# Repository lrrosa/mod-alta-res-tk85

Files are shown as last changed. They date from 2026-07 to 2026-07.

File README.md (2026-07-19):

# Mod Alta Resolução para o TK-85 ("Maldonado")

Reconstrução em **KiCad 10** do esquema elétrico da modificação de alta-resolução
gráfica para o **TK-85** (clone brasileiro do Sinclair ZX81), publicada por
**Milton Maldonado Jr.** na revista *Microhobby*.

O circuito acrescenta um framebuffer gráfico de alta resolução ao TK-85: três SRAMs
6116 compartilham o espaço de endereços da ROM principal (2364 — que contém o BASIC
e também as tabelas de caracteres) e são varridas por contadores sincronizados com a
geração de vídeo, dando uma definição comparável à de micros bem mais caros da época.

> **Status:** esquema verificado (ERC 0/0), PCB roteada (DRC 0/0) e Gerbers prontos
> para fabricação — falta montar e testar em hardware real.
> Veja [Estado do projeto](#estado-do-projeto).

---

## Estrutura do repositório

```
mod-alta-res-tk85/
├── kicad/                     Projeto KiCad 10
│   ├── mod_tk85_hires.kicad_sch    Esquema (folha única)
│   ├── mod_tk85_hires.kicad_pcb    Placa (roteada, 2 camadas, DRC limpo)
│   ├── mod_tk85_hires.kicad_pro    Projeto
│   ├── sym-lib-table               Tabela de símbolos (caminhos ${KIPRJMOD})
│   └── sym/                        Símbolos personalizados (ROM 2364, SRAM 6116)
├── esquemas/                  Esquema e placa exportados (PDF e SVG)
├── fabricacao/                Gerbers + furação (zip pronto para fábrica)
├── docs/                      Documentação, errata, BOM, mecânica
└── README.md
```

## Como abrir

Abra `kicad/mod_tk85_hires.kicad_pro` no KiCad 10. Os símbolos das memórias vêm da
biblioteca local em `kicad/sym/` (referenciada por caminho relativo `${KIPRJMOD}`, de
modo que o projeto pode ser movido ou clonado sem quebrar). Os demais símbolos (74xx,
Device, Connector, power) vêm das bibliotecas padrão do KiCad.

## Como funciona (resumo)

| Bloco | CI | Função |
|---|----|---|
| Framebuffer | U1–U3 (6116) | 3× 2 KB de SRAM gráfica, no espaço das tabelas de caracteres |
| ROM principal | U4 (2364) | ROM original do TK-85 (BASIC + caracteres), remanejada para a placa do mod |
| Contadores de vídeo | U5, U6 (74LS93) | Geram o endereço de varredura sincronizado ao vídeo |
| Multiplexador | U7 (74LS157) | Chaveia endereço: CPU (RFSH=1) × contadores (RFSH=0) |
| Decodificador | U8 (74LS138) | Seleciona qual das 3 SRAMs (`/CS0..2`) via A11/A12 |
| Cola lógica | U9 (74LS00) | Inversor de A14 para gerar `RAM CS` |
| Ajuste de reset | RV1 (22K) | Trimpot de temporização do reset dos contadores (errata) |

A conexão física com o TK-85 é feita por um **interposer pass-through**: os dois
pentes de 12 pinos (`IC2_PINS_1_12`, `IC2_PINS_13_24`) encaixam no soquete da ROM
principal (IC2) do TK-85, e a ROM 2364 encaixa por cima — cada pino do soquete é
eletricamente o mesmo nó do pino correspondente da ROM.

Descrição detalhada em [`docs/descricao-circuito.md`](docs/descricao-circuito.md).

## Errata

O artigo tem alguns erros, omissões e ambiguidades, já **corrigidos** aqui. Não os
"desfaça" comparando com a revista. Detalhes em
[`docs/correcoes-errata.md`](docs/correcoes-errata.md). Em resumo:

- `/WE` das 6116 → `WR` do Z80 (pino 22); `/OE` das 6116 → GND (omissão do artigo).
- Trimpot de 15–22 K no reset dos dois 74LS93 (`RV1`).
- Pino 9 do primeiro 74LS93 → **pino 5** do 74LS157 (o texto do artigo diz pino 9).
- `/CS` da ROM (pino 20 do IC2) ligado à ROM `U4` — necessário porque nesta
  implementação a ROM é remanejada para a placa do mod.

## Estado do projeto

- [x] Esquema elétrico em KiCad 10, com ERC limpo (0 erros / 0 avisos)
- [x] Nets com nomes significativos, desacoplamento e entradas não usadas amarradas
- [x] BOM ([`docs/bom.csv`](docs/bom.csv))
- [x] PCB: contorno (medido sobre a placa real) e posicionamento — ver
      [`docs/mecanica.md`](docs/mecanica.md)
- [x] PCB: roteamento completo em 2 camadas, DRC zerado (0 violações elétricas,
      0 pads desconectados); silk revisado
- [x] Gerbers e furação prontos para fabricação
      ([`fabricacao/`](fabricacao/))
- [ ] Montagem e teste em hardware real

## Créditos

- **Circuito original:** Milton Maldonado Jr. (*Microhobby*).
- **Reconstrução do esquema em KiCad:** Leonardo Roman da Rosa.

## Licença

Este projeto de hardware é licenciado sob a **CERN Open Hardware Licence v2 —
Strongly Reciprocal** (`CERN-OHL-S-2.0`). Veja o arquivo [`LICENSE`](LICENSE).

Conforme a seção 3.3 da licença, a localização da fonte (*Source Location*) deste
projeto é: <https://github.com/lrrosa/mod-alta-res-tk85>. Se você distribuir produtos
ou projetos derivados, mantenha as atribuições e disponibilize as fontes completas
sob a mesma licença.

> O material de referência original (o artigo da *Microhobby* e os datasheets dos
> componentes) **não** é redistribuído aqui por ser protegido por direitos autorais.
> Veja [`docs/referencias.md`](docs/referencias.md).

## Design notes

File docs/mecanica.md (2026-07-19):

# Mecânica — contorno, alturas e empilhamento

Este documento registra as medidas físicas que definiram o contorno da placa e o
esquema de montagem do interposer. As medidas foram tiradas de uma foto calibrada da
placa do TK-85 (calibração pelo passo de 2,54 mm dos DIPs; escala conferida no
DIP-40 do Z80 — erro estimado ±2–3%).

## Sistema de coordenadas

Tudo é medido em **mm relativos ao centro do IC2** (a ROM principal), com
+x para leste (em direção ao Z80) e +y para sul (em direção ao teclado). No arquivo
`kicad/mod_tk85_hires.kicad_pcb`, o centro do IC2 corresponde à posição absoluta
(150, 100).

## Contorno (forma de T)

- **Língua** (sobre o IC2): x −11,1…+10 / y −20…+17,5 — carrega os dois pentes do
  interposer, `U9` e `U6`.
- **Corpo**: x −70…+35,6 / y +17,5…+59 — paira sobre as fileiras de TTL (IC17…) e
  de RAM (IC30–37) do TK-85.
- **Recorte SE**: para x > +15,5 o corpo pára em y = +44, desviando do capacitor
  de tântalo ("gota") ao lado do IC9.

## Obstáculos altos medidos (sob ou ao lado da placa)

| Obstáculo | Posição (mm rel. IC2) | Altura aprox. | Situação |
|---|---|---|---|
| Capacitor azul deitado | x +11,5…+24,5 / y −17…−8 | ~10–11 mm | **Fora** do contorno (a língua pára em x = +10) |
| 2716 + soquete (IC3) | x −31…−12,5 / y −15…+17 | ~13 mm | **Fora** (corpo começa em y = +17,5) |
| Z80 | x +36,7… | — | Fora (borda leste em +35,6, folga ~1 mm) |
| Capacitor "gota" | x +17…+20,5 / y +46…+56 | ~9 mm | Fora (recorte SE) |
| ICs 30–37 **soquetados** | y ≈ +42…+61 | ~8–9,5 mm | **Sob a placa** — ver empilhamento |
| Fileira de TTL (IC17…) | y ≈ +17,5…+35 | ~4,5 mm | Sob a placa, baixa |

## Empilhamento do interposer e teto do gabinete

**Medições no gabinete real (2026-07-18):** sobram **~12 mm** livres tanto acima da
ROM (IC2) quanto acima dos ICs 30–37. Todos esses CIs estão **soquetados** de
fábrica (soquetes de lâmina marrons, ~3,5–4 mm — inclusive o IC2 e o 2716), com o
topo a ~8–9,5 mm da placa-mãe. O teto útil é portanto de **~20–21 mm** em toda a
região ocupada pela placa do mod.

**Pilha adotada** (contorno atual mantido):

| Camada | Altura acumulada sobre a placa-mãe |
|---|---|
| Soquete existente do IC2 (lâmina, de fábrica) | ~3,5–4 mm |
| Soquete torneado extra (espaçador) | ~7,5–8 mm |
| Pentes do interposer sob a placa do mod | vão total **~10–11 mm** |
| Placa do mod (1,6 mm) | ~12–13 mm |
| CIs do mod **soldados** (~4,5 mm) | topo a **~16,5–17 mm** ✓ |
| ROM em soquete de lâmina baixo na placa do mod | topo a **~20 mm** — no limite, cabe |

- O vão de ~10–11 mm passa sobre os ICs 30–37 soquetados (~8–9,5 mm) com folga de
  1–2,5 mm.
- Os CIs do mod (TTLs e 6116) devem ser **soldados sem soquete** para preservar o
  teto. Só a ROM — o chip original transplantado — usa soquete, de lâmina e perfil
  baixo.
- Pino torneado encaixa em soquete de lâmina, mas confira o aperto do contato; se
  ficar frouxo, vale trocar o soquete do IC2 por um torneado.
- Estabilidade: a placa fica em balanço apoiada só no soquete do IC2. Recomenda-se
  um **pé de apoio** (espaçador de nylon com base adesiva, ou bloco de espuma) sob
  o canto sudoeste do corpo.

## Montagem da ROM sobre a língua (interposer)

Os dois pentes do interposer estão em geometria DIP-24 (600 mil) e carregam
**exatamente as mesmas nets, pino a pino, do soquete `U4`** — consequência do
interposer pass-through. Ou seja: a ROM 2364 pode ser encaixada **diretamente
sobre a língua**, em cima de `U9` e `U6`, dispensando o soquete `U4` (que fica
despopulado; **nunca** popular os dois ao mesmo tempo com duas ROMs).

A peça que realiza isso é um **soquete DIP-24 torneado com terminais wire-wrap**
(postes de 2 ou 3 níveis, 10–17 mm): o corpo fica no topo da placa como soquete da
ROM, e os postes atravessam a placa e viram os pinos macho do interposer por baixo.
Exemplos: Mill-Max série 123 (123-93-624-41-001000), Preci-Dip 110-93-624-41-001000;
como alternativa mais fácil de encontrar, **duas barras SIP 1×12 torneadas de
terminal longo** ("round pin female header, wire-wrap/long pin") cortadas na medida.

Alturas nessa configuração (**medidas sobre a placa-mãe do TK-85**; topo da placa
do mod fica a ~11,6–12,6 mm):

- Assento do soquete wire-wrap: ~4,5–5 mm sobre a placa do mod — os CIs
  `U9`/`U6` soldados (~4,3 mm) passam por baixo **no limite** (folga 0,2–0,7 mm).
- Topo da ROM: 11,6–12,6 + 4,5–5 + 4,5 ≈ **20,6–22 mm** — **igual ou acima do
  teto de ~20–21 mm**. Com um soquete extra empilhado (para dar folga sobre
  U9/U6), vai a ~24 mm — **não cabe de jeito nenhum**.
- **Conclusão: com o teto medido, esta opção é desaconselhada.** Fica registrada
  pela equivalência elétrica (vale para gabinetes modificados ou uso sem tampa);
  a montagem recomendada é a ROM no soquete `U4` (topo a ~19–20,6 mm).
- Por baixo, os postes atravessam o soquete-espaçador e entram no soquete original
  do IC2. Postes wire-wrap são quadrados (~0,64 mm): encaixam bem em soquetes de
  **lâmina** (o espaçador e o soquete original do TK-85); evite usar soquete
  torneado como espaçador nesse caso, pois o furo torneado é para pino redondo.

## RV1 — ajuste por cima

`RV1` usa o Bourns **3266W** (ajuste pelo topo). A variante lateral (3266P) foi
descartada porque o parafuso ficava voltado para o interior da placa, inacessível
com os soquetes vizinhos populados.

**Altura:** o 3266W tem **8,26 mm** de corpo — topo a ~19,9–20,9 mm sobre a
placa-mãe, no **mesmo grupo crítico da ROM** frente ao teto de ~20–21 mm. Antes de
soldar, faça um ensaio a seco: com a pilha do interposer montada e a tampa
fechando, é preciso haver **≥ 8,3 mm** livres acima do topo da placa do mod na
região do RV1. Se faltar, os planos B são: (a) trocar por um trimpot de volta
única com ajuste por cima e ~5 mm de altura (ex.: Piher PT-6-V — exige retrabalho
dos pads naquele canto), ou (b) montar o trimpot fora da placa, por 3 fios curtos
nos pads (estilo "teia de aranha", fiel ao artigo).

## Roteamento

Duas camadas, roteado por autorouter (Freerouting 2.2.4) com acabamento manual,
DRC do KiCad **zerado** (0 violações elétricas, 0 pads desconectados):

- Trilhas de sinal **0,25 mm**; `+5V` e `GND` **0,6 mm**; isolamento mínimo
  **0,13 mm**; vias 0,6/0,3 mm — tudo dentro da capacidade de qualquer fabricante
  comum de PCB (limite típico 0,127 mm).
- `GND` é roteado como trilha **e** reforçado por pours nas duas faces.
- A checagem `starved_thermal` foi rebaixada para aviso: quatro pads de GND ficam
  com um único raio térmico da zona, mas todos têm também conexão plena por
  trilha — eletricamente sólidos; o alívio térmico ainda ajuda na soldagem.

## J1 (sinais do TK-85)

Barra de 8 pinos em ângulo reto na borda sul, com os pinos apontando para a frente
do micro (lado do teclado). Os fios voadores para A14/A15/MREQ/RFSH/WR (CPU),
RAM CS, clock de vídeo (IC-11) e clock de 60 Hz (IC-24) saem por ali.

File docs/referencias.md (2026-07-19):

# Referências

O material de referência abaixo foi usado na reconstrução do esquema. Ele **não é
redistribuído neste repositório** por ser protegido por direitos autorais — está
listado apenas para atribuição e para quem quiser buscá-lo nas fontes originais.

## Artigo original

- **"Alta-Resolução no TK-85"** (Partes I, II e III) — Milton Maldonado Jr., revista
  *Microhobby*. É a descrição do circuito e do procedimento de montagem/ajuste que este
  projeto implementa. Disponível para consulta no acervo do Datassette:
  <https://datassette.org/pt-br/revistas/informatica/br-brasil/microhobby/projetos/alta-resolucao-no-tk-85>

## Datasheets dos componentes

- ROM **2364** (ROM de máscara de 8 KB — a ROM principal do TK-85, IC2, com o
  BASIC/sistema e as tabelas de caracteres). Datasheet MOS 2364 (fev. 1980):
  <https://archive.org/details/mos_2364_rom_feb_1980>
- SRAM **6116** (2 KB × 8) — as três memórias do framebuffer. Datasheet Renesas
  6116SA/LA: <https://www.renesas.com/en/document/dst/6116sala-data-sheet>
- Famílias TTL **74LS00, 74LS93, 74LS138, 74LS157** — datasheets dos respectivos
  fabricantes.

## Placa hospedeira

- **TK-85 revisão K** — esquema da placa do TK-85, **redesenhado por Daniel José
  Viana ("Danjovic")**; não é o esquema original de fábrica. Usado como referência
  para localizar os sinais tomados por `J1`: A14, A15, MREQ, RFSH, WR, clock de
  vídeo e clock de 60 Hz. Disponível no acervo do Datassette:
  <https://datassette.org/pt-br/manuais/microdigital-eletronica/tk82c-tk83-tk85/hardware/br-brasil/tk85-esquema-eletrico-rev-k>

## Nota sobre direitos autorais

Este repositório contém apenas trabalho derivado próprio (o esquema em KiCad e a
documentação). Os documentos originais acima pertencem aos seus respectivos autores e
detentores de direitos.

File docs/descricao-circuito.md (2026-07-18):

# Descrição do circuito

Este documento descreve o funcionamento do mod e o significado dos sinais do esquema.
A fonte da lógica é o artigo original de Milton Maldonado Jr.; a nomenclatura de nets
abaixo foi padronizada nesta reconstrução.

## Ideia geral

O IC2 do TK-85 é a **ROM principal** do micro (2364, 8 KB): contém o BASIC/sistema e
também as tabelas de bitmap dos caracteres, lidas pela lógica de vídeo durante a
geração da imagem (como no ZX81). O mod intercepta o soquete dessa ROM e acrescenta
**três SRAMs 6116** (6 KB) mapeadas de forma a substituir as tabelas de caracteres
durante a varredura. Assim é possível redefinir dinamicamente os bitmaps (POKE nas
6116) e obter 256×192 pixels de alta resolução, sem consumir os 16 KB de RAM do
usuário.

O ponto delicado é o **endereçamento**: durante a geração da imagem, quem endereça as
memórias não é a CPU, e sim contadores sincronizados ao vídeo.

## Blocos

### Framebuffer — U1, U2, U3 (6116)
Três SRAMs de 2 KB. Endereços baixos `A0–A8` são compartilhados com a ROM (vêm do
soquete do IC2). `A9`/`A10` de cada SRAM vêm do multiplexador (`RAM_A9`, `RAM_A10`).
Seleção de chip por `/CS0`, `/CS1`, `/CS2` (do 74LS138). `/WE = WR` do Z80, `/OE = GND`
(ver errata). Dados `D0–D7` compartilhados com a ROM e o soquete.

### ROM principal — U4 (2364)
A ROM original do TK-85 (BASIC + tabelas de caracteres), remanejada para a placa do
mod. Endereços `A0–A8` iguais aos das SRAMs; `A9–A12` vêm direto da CPU (soquete).
`/CS = CS_ROM` (pino 20 do soquete).

### Contadores de vídeo — U5, U6 (74LS93)
- `U5` (CI-A): recebe o **clock de vídeo** (`CLK_VID`) em CP0; Q0→CP1 forma o contador
  de 4 bits; Q3 (`CT_CARRY`) faz o "carry" para o CI-B.
- `U6` (CI-B): clocado por `CT_CARRY`; saídas `VQ0–VQ3` são o endereço de vídeo que
  alimenta o multiplexador.
- Reset: `R0(1)` dos dois CIs no nó `CNT_RST`, alimentado pelo clock de 60 Hz através do
  trimpot `RV1`. `R0(2)` de ambos amarrado a `+5V` (determinístico; era flutuante).

### Multiplexador de endereços — U7 (74LS157)
Seleciona, conforme `RFSH`:
- `RFSH = 1` (CPU acessando as memórias): passa `A9–A12` da CPU.
- `RFSH = 0` (geração de imagem): passa `VQ0–VQ3` dos contadores.

Saídas: `RAM_A9`/`RAM_A10` (para as SRAMs) e `SEL_A0`/`SEL_A1` (para o decodificador).
Enable `/E` (pino 15) em GND (sempre ativo).

### Decodificador de banco — U8 (74LS138)
Entradas `A0/A1 = SEL_A0/SEL_A1` (o par A11/A12 já multiplexado), `A2 = GND`. Habilitação
`G1 = A15`, `/G2A = A14`, `/G2B = MREQ`. Saídas `O0–O2 = /CS0../CS2`. `O3–O7` não usadas.

### Cola lógica — U9 (74LS00)
Apenas a porta A é usada: `NAND(A14, A14) = /A14`, que gera o sinal `RAM CS` de volta ao
TK-85. As outras três portas têm entradas amarradas a GND e saídas em no-connect.

### Interface com o TK-85 — J1
Barra de 8 pinos com os sinais tomados de outros pontos da placa do TK-85:
`A14, A15, RAM CS, MREQ, RFSH, WR, CLK_60, CLK_VID`.

## Referência de nets

| Net | Significado |
|-----|---|
| `A0`–`A8` | Endereços baixos compartilhados (soquete → ROM + SRAMs) |
| `A9`–`A12` | Endereços altos da CPU (soquete → ROM + entradas `I1` do mux) |
| `D0`–`D7` | Barramento de dados (soquete ↔ ROM ↔ SRAMs) |
| `CS_ROM` | `/CS` da ROM 2364 (pino 20 do IC2) |
| `RAM_A9`, `RAM_A10` | Endereços A9/A10 das SRAMs (saída do mux) |
| `SEL_A0`, `SEL_A1` | A11/A12 multiplexados → entradas do decodificador |
| `CS0`, `CS1`, `CS2` | Seleção das três SRAMs (`/CS`, do 74LS138) |
| `VQ0`–`VQ3` | Endereço de vídeo (saídas do contador CI-B) |
| `CT_CARRY` | Q3 do CI-A → CP0 do CI-B (cascata dos contadores) |
| `CTA_Q0` | Q0→CP1 do CI-A (realimentação interna do contador) |
| `CNT_RST` | Reset dos contadores (via trimpot `RV1`, do clock de 60 Hz) |
| `RFSH`, `MREQ`, `WR` | Sinais de controle do Z80 |
| `A14`, `A15` | Endereços altos da CPU para o decodificador/cola |
| `RAM CS` | Sinal gerado (`/A14`) devolvido ao TK-85 |
| `CLK_VID`, `CLK_60` | Clock de vídeo (≈15750 Hz) e clock de 60 Hz |

## Desacoplamento

Um capacitor de 100 nF por CI (`C1–C9`) e um eletrolítico de 47 µF de bulk (`C10`).
São acréscimo deste projeto em relação ao artigo — ver a seção 5 de
[`correcoes-errata.md`](correcoes-errata.md).

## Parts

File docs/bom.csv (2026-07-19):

Ref | Valor | Footprint | Qtd
C1-C9 | 100nF | Capacitor_THT:C_Disc_D5.0mm_W2.5mm_P5.00mm | 9
C10 | 47uF | Capacitor_THT:CP_Radial_D6.3mm_P2.50mm | 1
IC2_PINS_1_12 | IC2 pinos 1-12 | Connector_PinSocket_2.54mm:PinSocket_1x12_P2.54mm_Vertical | 1
IC2_PINS_13_24 | IC2 pinos 13-24 | Connector_PinSocket_2.54mm:PinSocket_1x12_P2.54mm_Vertical | 1
J1 | Sinais do TK-85 | Connector_PinHeader_2.54mm:PinHeader_1x08_P2.54mm_Horizontal | 1
RV1 | 22K | Potentiometer_THT:Potentiometer_Bourns_3266W_Vertical | 1
U1-U3 | 6116 | Package_DIP:DIP-24_W15.24mm_Socket | 3
U4 | 2364 (IC2) | Package_DIP:DIP-24_W15.24mm_Socket | 1
U5,U6 | 74LS93 | Package_DIP:DIP-14_W7.62mm_Socket | 2
U7 | 74LS157 | Package_DIP:DIP-16_W7.62mm_Socket | 1
U8 | 74LS138 | Package_DIP:DIP-16_W7.62mm_Socket | 1
U9 | 74LS00 | Package_DIP:DIP-14_W7.62mm_Socket | 1

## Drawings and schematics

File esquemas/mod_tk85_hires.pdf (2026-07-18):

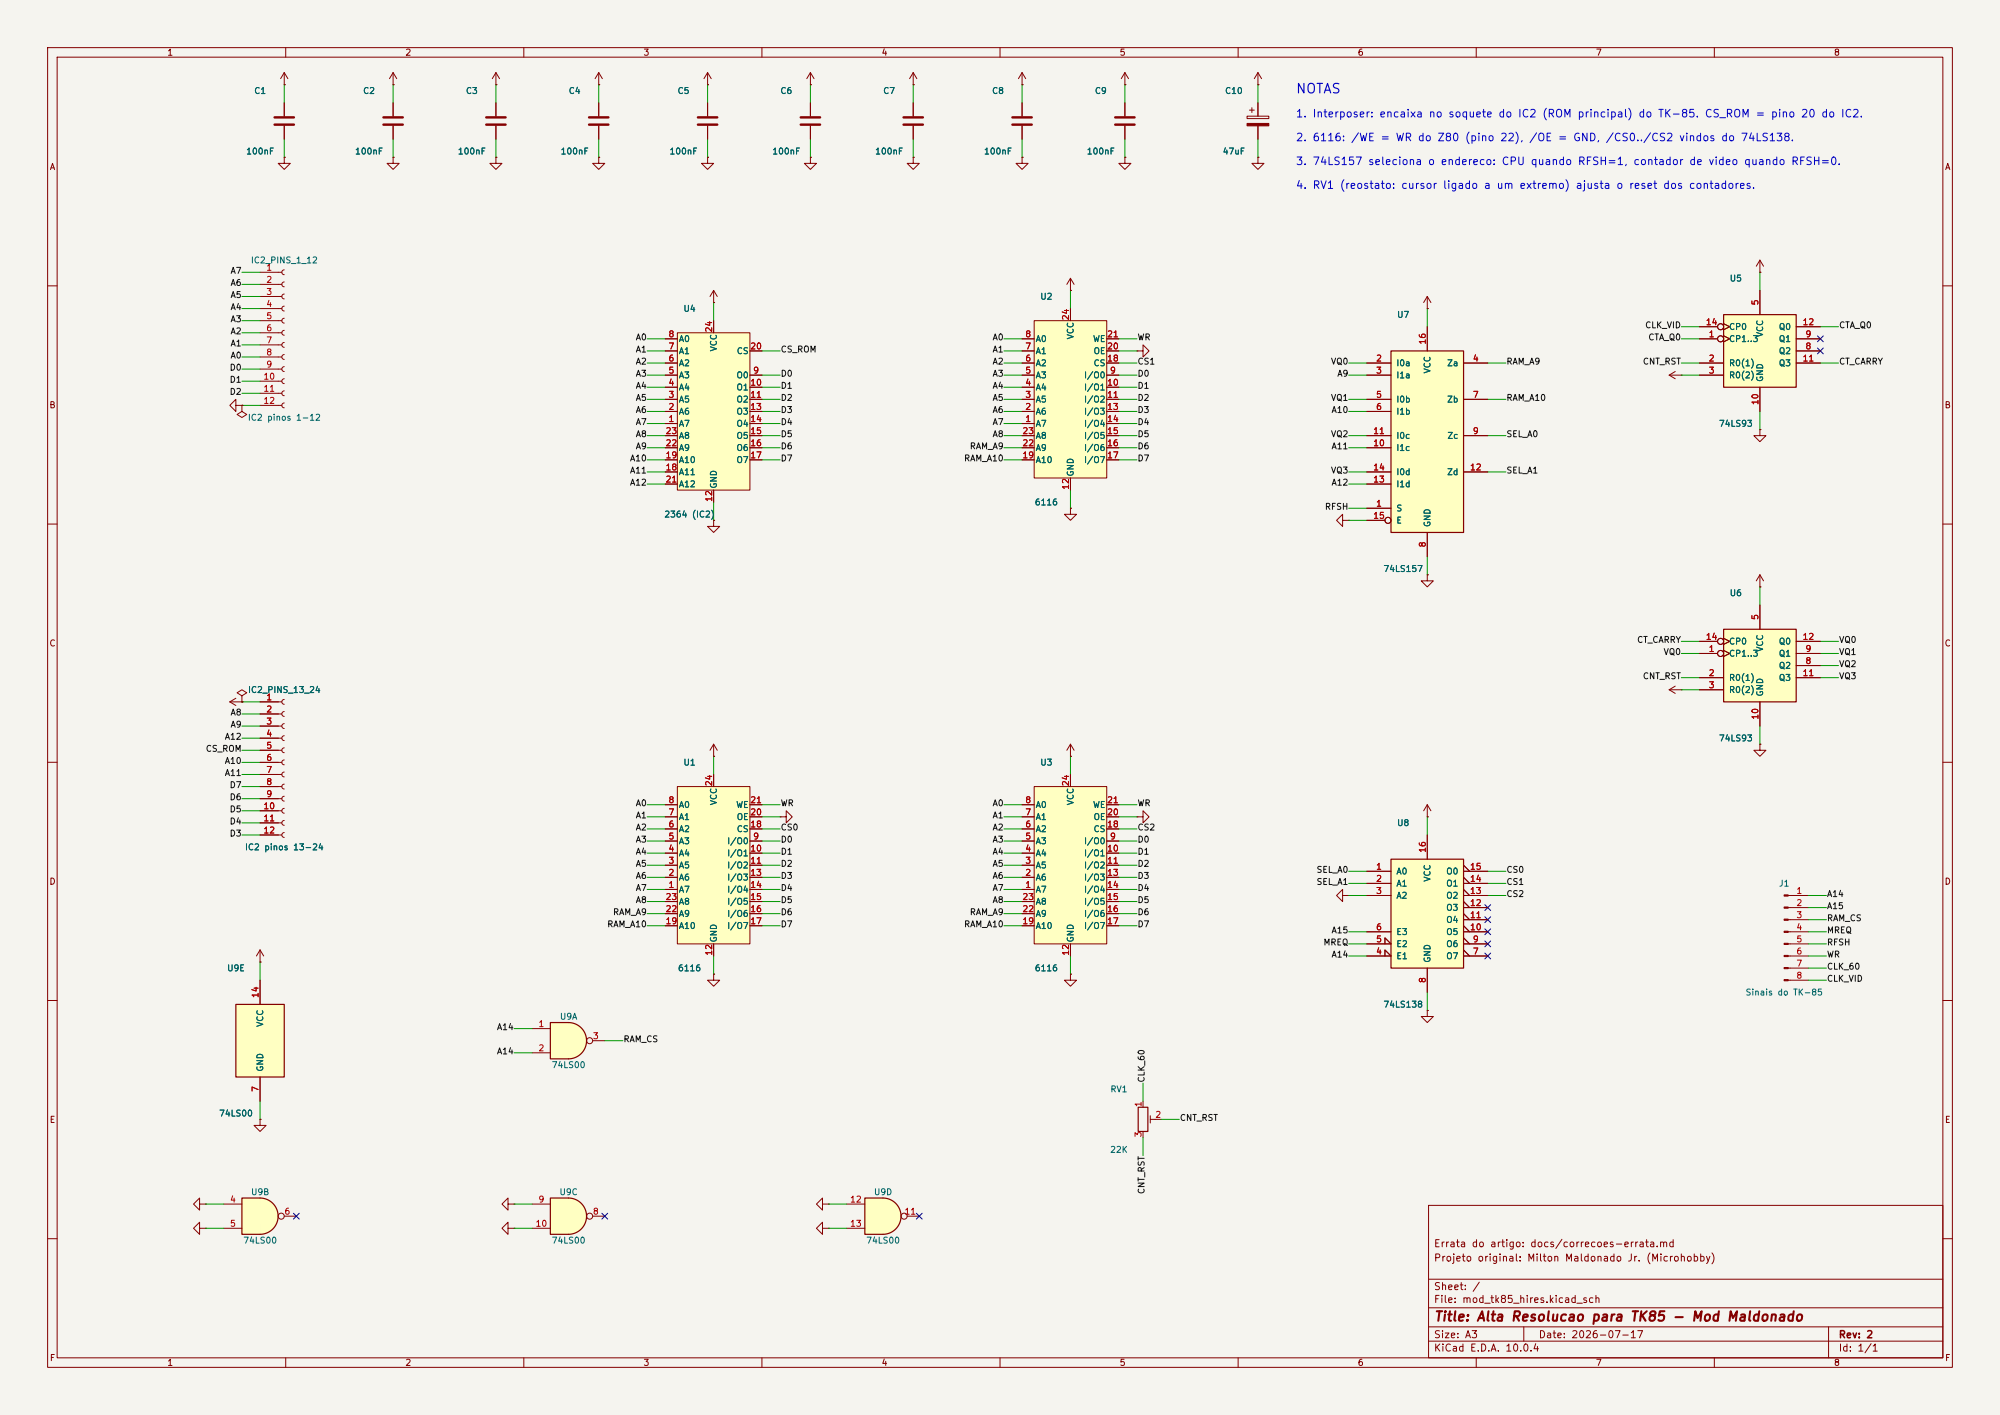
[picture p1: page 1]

4. RV1 (reostato: cursor ligado a um extremo) ajusta o reset dos contadores. C1

1. Interposer: encaixa no soquete do IC2 (ROM principal) do TK-85. CS_ROM = pino 20 do IC2.

2. 6116: /WE = WR do Z80 (pino 22), /OE = GND, /CS0../CS2 vindos do 74LS138.

3. 74LS157 seleciona o endereco: CPU quando RFSH=1, contador de video quando RFSH=0.

Errata do artigo: docs/correcoes-errata.md
Projeto original: Milton Maldonado Jr. (Microhobby)

Sheet: /
File: mod_tk85_hires.kicad_sch
Title: Alta Resolucao para TK85 - Mod Maldonado

Size: A3 | Rev: 2
KiCad E.D.A. 10.0.4 | Id: 1/1

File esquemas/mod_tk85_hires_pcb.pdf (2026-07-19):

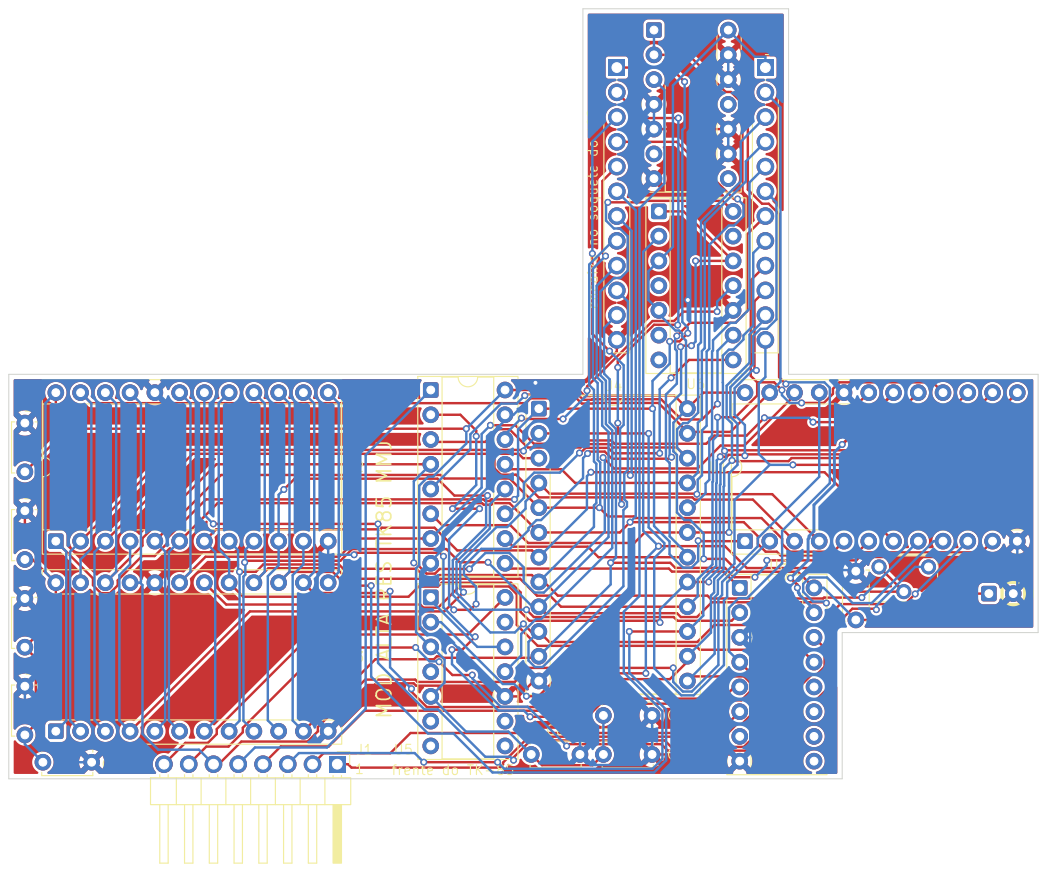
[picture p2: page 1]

Z80> encaixa no soquete do IC2 MOD ALTA RES TK85 MMJ

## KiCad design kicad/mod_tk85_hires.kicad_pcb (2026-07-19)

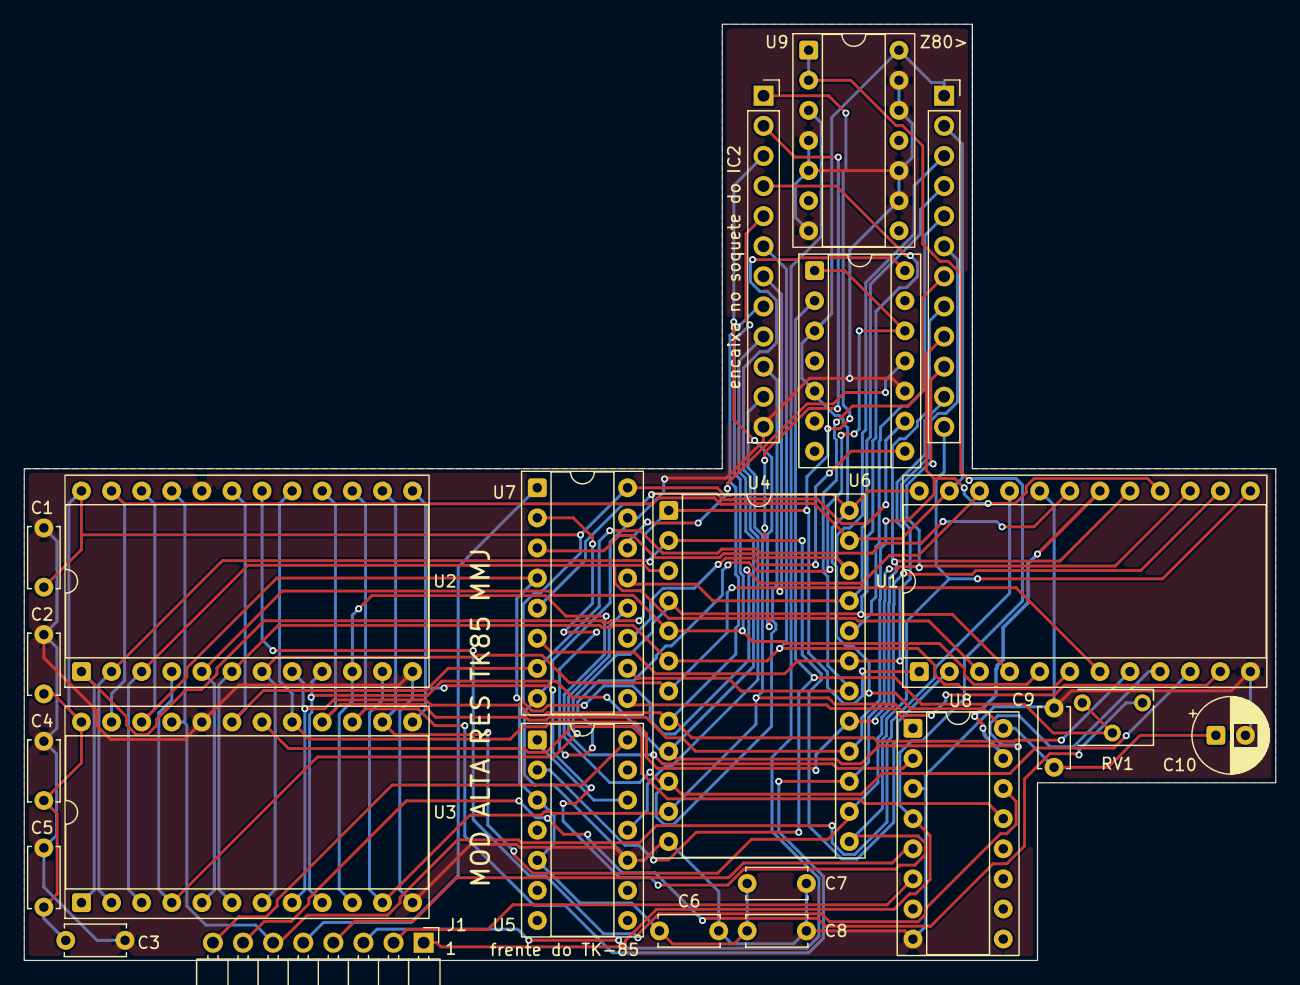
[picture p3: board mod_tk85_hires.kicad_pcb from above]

Board: 2 copper layers, 105.6 x 79.0 mm, 23 parts (0 on the bottom side), 46 nets.

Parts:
C1, C2, C3, C4, C5, C6, C7, C8, C9: C_Disc_D5.0mm_W2.5mm_P5.00mm
C10: CP_Radial_D6.3mm_P2.50mm
IC2_PINS_1_12, IC2_PINS_13_24: PinSocket_1x12_P2.54mm_Vertical
J1: PinHeader_1x08_P2.54mm_Horizontal
RV1: 22K; Potentiometer_Bourns_3266W_Vertical
U1, U2, U3, U4: DIP-24_W15.24mm_Socket
U5, U6, U9: DIP-14_W7.62mm_Socket
U7, U8: DIP-16_W7.62mm_Socket

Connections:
+5V: C1.1, C2.1, C3.1, C4.1, C5.1, C6.1, C7.1, C8.1, C9.1, C10.1, IC2_PINS_13_24.1, U1.24, U2.24, U3.24, U4.24, U5.3, U5.5, U6.3, U6.5, U7.16, U8.16, U9.14
/A0: IC2_PINS_1_12.8, U1.8, U2.8, U3.8, U4.8
/A1: IC2_PINS_1_12.7, U1.7, U2.7, U3.7, U4.7
/A2: IC2_PINS_1_12.6, U1.6, U2.6, U3.6, U4.6
/A3: IC2_PINS_1_12.5, U1.5, U2.5, U3.5, U4.5
/A4: IC2_PINS_1_12.4, U1.4, U2.4, U3.4, U4.4
/A5: IC2_PINS_1_12.3, U1.3, U2.3, U3.3, U4.3
/A6: IC2_PINS_1_12.2, U1.2, U2.2, U3.2, U4.2
/A7: IC2_PINS_1_12.1, U1.1, U2.1, U3.1, U4.1
/A8: IC2_PINS_13_24.2, U1.23, U2.23, U3.23, U4.23
/A9: IC2_PINS_13_24.3, U4.22, U7.3
/A10: IC2_PINS_13_24.6, U4.19, U7.6
/A11: IC2_PINS_13_24.7, U4.18, U7.10
/A12: IC2_PINS_13_24.4, U4.21, U7.13
/A14: J1.1, U8.4, U9.1, U9.2
/A15: J1.2, U8.6
/CLK_60: J1.7, RV1.1
/CLK_VID: J1.8, U5.14
/CNT_RST: RV1.2, RV1.3, U5.2, U6.2
/CS0: U1.18, U8.15
/CS1: U2.18, U8.14
/CS2: U3.18, U8.13
/CS_ROM: IC2_PINS_13_24.5, U4.20
/CTA_Q0: U5.1, U5.12
/CT_CARRY: U5.11, U6.14
/D0: IC2_PINS_1_12.9, U1.9, U2.9, U3.9, U4.9
/D1: IC2_PINS_1_12.10, U1.10, U2.10, U3.10, U4.10
/D2: IC2_PINS_1_12.11, U1.11, U2.11, U3.11, U4.11
/D3: IC2_PINS_13_24.12, U1.13, U2.13, U3.13, U4.13
/D4: IC2_PINS_13_24.11, U1.14, U2.14, U3.14, U4.14
/D5: IC2_PINS_13_24.10, U1.15, U2.15, U3.15, U4.15
/D6: IC2_PINS_13_24.9, U1.16, U2.16, U3.16, U4.16
/D7: IC2_PINS_13_24.8, U1.17, U2.17, U3.17, U4.17
/MREQ: J1.4, U8.5
/RAM_A9: U1.22, U2.22, U3.22, U7.4
/RAM_A10: U1.19, U2.19, U3.19, U7.7
/RAM_CS: J1.3, U9.3
/RFSH: J1.5, U7.1
/SEL_A0: U7.9, U8.1
/SEL_A1: U7.12, U8.2
/VQ0: U6.1, U6.12, U7.2
/VQ1: U6.9, U7.5
/VQ2: U6.8, U7.11
/VQ3: U6.11, U7.14
/WR: J1.6, U1.21, U2.21, U3.21
GND: C1.2, C2.2, C3.2, C4.2, C5.2, C6.2, C7.2, C8.2, C9.2, C10.2, IC2_PINS_1_12.12, U1.12, U1.20, U2.12, U2.20, U3.12, U3.20, U4.12, U5.10, U6.10, U7.8, U7.15, U8.3, U8.8, U9.4, U9.5, U9.7, U9.9, U9.10, U9.12, U9.13

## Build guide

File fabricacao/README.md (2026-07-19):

# Arquivos de fabricação

`mod_tk85_hires_gerbers.zip` contém os Gerbers (X2) e a furação Excellon prontos
para envio a qualquer fabricante comum de PCB (JLCPCB, PCBWay, etc.). Os mesmos
arquivos estão soltos em [`gerbers/`](gerbers/).

## Especificação da placa

| Parâmetro | Valor |
|---|---|
| Camadas | 2 (F.Cu / B.Cu) |
| Espessura | 1,6 mm |
| Dimensões | ~105 × 79 mm (contorno em T, ver `Edge_Cuts`) |
| Trilha mínima | 0,25 mm (sinais); 0,6 mm (+5V/GND) |
| Isolamento mínimo | 0,13 mm |
| Furo mínimo | 0,3 mm (vias 0,6/0,3) |
| Furos não metalizados | nenhum |
| Acabamento | qualquer (HASL serve; a placa é toda THT) |

Nada fora do padrão barato dos fabricantes (capacidade típica: trilha/isolamento
0,127 mm, furo 0,3 mm). DRC do KiCad zerado na revisão que gerou estes arquivos.

## Observações de montagem

- Os CIs do mod são **soldados sem soquete** (exceto a ROM 2364, em soquete de
  lâmina baixo) — restrição de altura do gabinete; ver
  [`../docs/mecanica.md`](../docs/mecanica.md).
- Os dois pentes do interposer (`IC2_PINS_*`) usam barras de pino torneado longo,
  inseridas por cima, com um soquete torneado extra como espaçador no TK-85.
- A pinagem do conector `J1` está serigrafada no **verso** da placa.

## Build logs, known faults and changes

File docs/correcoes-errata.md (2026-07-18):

# Correções / Errata

O artigo original (*Alta-Resolução no TK-85*, Milton Maldonado Jr., *Microhobby*)
contém alguns erros, omissões e ambiguidades. As correções abaixo **já estão
aplicadas** neste projeto — não as reverta ao comparar com a revista.

## 1. `/WE` e `/OE` das SRAMs 6116 (omissão do artigo)

- O `/WE` (pino 21) das três 6116 vai ao **`WR` do Z80 (pino 22 da CPU)**.
- O `/OE` (pino 20) das três 6116 vai ao **GND**.

**Por que isso não aparece no artigo:** o roteiro de montagem (Parte II) liga os
pinos 18 das 6116 (`/CS0..2`, na tabela do 74LS138) e os pinos 19 e 22 (`A10'` e
`A9'`, na tabela do 74LS157), mas não diz o que fazer com os pinos 20 e 21; e o
"Esquema Completo" (Microhobby, pág. 33) mostra apenas a lógica (74LS157, 74LS138 e
os dois 74LS93) — as 6116 não aparecem nele. Sem essas duas ligações o circuito não
funciona: sem `/WE` a CPU nunca escreve no framebuffer, e com `/OE` flutuando a
leitura fica indefinida.

**Por que estas ligações:** `WR` é o único strobe de escrita do Z80, e a escrita já é
qualificada chip a chip pelo `/CS` vindo do 74LS138 (que por sua vez só ativa com
`MREQ` e a janela de endereços A15/A14 correta) — é a forma canônica de pendurar SRAM
num barramento Z80. `/OE` em GND é seguro pela tabela-verdade da 6116: as saídas só
habilitam com `/CS`=0 **e** `/WE`=1; chip desselecionado (standby) ou em escrita fica
em alta impedância (`/OE` é *don't care* na escrita, conforme o datasheet). Como a
janela das SRAMs não se sobrepõe à da ROM, nunca há dois chips dirigindo o barramento
ao mesmo tempo, e não é preciso usar o `/RD` (que nem está entre os sinais tomados
do TK-85).

## 2. Trimpot de reset (RV1)

É necessário um trimpot de **15 a 22 kΩ** na ligação entre o pino 2 de ambos os 74LS93
e o pino 2 do IC-24 do TK-85 (que carrega o clock de 60 Hz). Esse é o `RV1` (22 K), que
ajusta a temporização do reset dos contadores. O procedimento de ajuste está descrito
na Parte III do artigo.

No esquema, o cursor do trimpot (pino 2) e o extremo não usado (pino 3) estão ligados ao
mesmo nó (`CNT_RST`). Isso é boa prática para trimpots usados como reostato: se o cursor
perder contato, a resistência vai ao máximo em vez de abrir o circuito.

## 3. Ambiguidade pino 9 vs. pino 5 do 74LS157

O texto do artigo manda ligar o **pino 9 do primeiro 74LS93** ao **pino 9 do 74LS157**,
mas isso está errado — o destino correto é o **pino 5 do 74LS157** (entrada `2A`/`I0b`).
A própria tabela do artigo se contradiz: lista "9 → 2A (pino 9)", mas `2A` do 74LS157 é
o pino **5**. As demais entradas da tabela (1A=pino 2, 3A=pino 11, 4A=pino 14) estão
corretas, confirmando que o pino 5 é o certo.

Neste projeto: `U6` pino 9 (Q1) → `U7` pino 5 (I0b), na net `VQ1`.

## 4. `/CS` da ROM principal (montagem em placa)

Na montagem "teia de aranha" do artigo, a ROM continua no soquete do TK-85 e o pino 20
dela (`/CS`, gerado pela lógica do próprio TK-85) não é tocado — por isso o artigo não
fala dele. Nesta implementação em placa, a ROM é remanejada para o soquete `U4` da
placa do mod, e o `/CS` precisa acompanhá-la: o **pino 20 do soquete do IC2** deve ser
ligado ao **pino 20 da ROM** (net `CS_ROM`). Sem essa ligação a ROM nunca é
selecionada e o TK-85 não dá boot.

Detalhe de leitura do esquema: o soquete do IC2 é desenhado como dois conectores de 12
posições. As posições 1–12 de `IC2_PINS_1_12` correspondem aos pinos 1–12 do IC2, e as
posições 1–12 de `IC2_PINS_13_24` correspondem aos pinos **24–13** (nessa ordem) — o
`/CS` (pino 20 do IC2) é a posição 5 desse segundo conector.

## 5. Capacitores de desacoplamento — C1 a C10 (acréscimo)

O artigo não prevê nenhum capacitor de desacoplamento — na montagem "teia de aranha",
os CIs ficam soldados sobre CIs do próprio TK-85 e aproveitam, mal ou bem, o
desacoplamento da placa hospedeira. Numa placa própria isso deixa de existir, e TTL da
família LS gera transientes de corrente consideráveis a cada comutação.

Este projeto acrescenta um **100 nF cerâmico por CI** (`C1`–`C9`, junto a cada
alimentação) e um **eletrolítico de 47 µF** de reserva de carga (`C10`). Ao comparar
com a revista: esses dez componentes não constam do artigo e **não devem ser
removidos** — são acréscimo intencional, prática padrão de projeto.

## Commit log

2026-07-17 Esquema KiCad 10 do mod de alta resolução para o TK-85 (Maldonado)
    Reconstrução verificada do esquema publicado na Microhobby por Milton
    Maldonado Jr., com correções sobre o projeto KiCad anterior:
    - /CS da ROM 2364 (pino 20 do IC2) ligado à ROM via interposer
    pass-through — estava eletricamente solto (a placa não daria boot)
    - Errata do artigo preservada: /WE=WR do Z80, /OE=GND nas 6116,
    trimpot RV1 no reset dos contadores, LS93 pino 9 -> LS157 pino 5
    - Desacoplamento acrescentado: 9x 100nF + 47uF de bulk
    - Entradas não usadas amarradas (R0(2) dos LS93, portas livres do LS00)
    - Nets nomeadas com significado (A0-A12, D0-D7, VQ0-VQ3, CS_ROM, ...)
    - Símbolos custom (2364/6116)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
    [bom.csv, mod_tk85_hires.kicad_sch]
2026-07-18 Ajustes de revisão do esquema (rev 2)
    Correções apontadas na revisão visual:
    - PWR_FLAGs soltos no canto inferior esquerdo removidos; agora ficam
    presos aos stubs de entrada de alimentação do interposer (pino 1 =
    +5V, pino 12 = GND), onde a energia realmente entra vinda do TK-85
    - J1 (Sinais do TK-85) movido para dentro da folha — os labels
    ultrapassavam a borda direita do A3
    - Legendas soltas consolidadas num bloco NOTAS no canto superior
    direito (área livre), eliminando sobreposição com U9E e RV1
    - Notas reescritas como descrição do projeto, sem justificar
    correções históricas; carimbo aponta docs/correcoes-errata.md
    - Reference/Value de símbolos com pinos verti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
    [mod_tk85_hires.kicad_sch]
2026-07-18 Afasta RV1 do carimbo da folha
    Movido de x=300 para x=240 (área livre abaixo do 74LS138), a pedido
    da revisão. Netlist idêntica, ERC 0/0, PDF e SVG reexportados.
    [mod_tk85_hires.kicad_sch]
2026-07-18 Adiciona licença CERN-OHL-S-2.0
    Texto oficial (SPDX) em LICENSE; README atualizado com a seção de
    licença e a Source Location exigida pela seção 3.3.
2026-07-18 Revisão da documentação: atribuição, clareza e justificativas
    - referencias.md: o esquema do TK-85 rev. K é redesenho de Daniel
    José Viana (Danjovic), não o esquema original de fábrica
    - correcoes-errata.md: remove menções a "projeto anterior"; seção do
    /CS reescrita em termos do pino 20 do soquete do IC2 (a numeração
    posição 5 = pino 20 agora é explicada, não pressuposta)
    - correcoes-errata.md: adiciona a justificativa técnica de /WE=WR e
    /OE=GND — o roteiro do artigo liga os pinos 18, 19 e 22 das 6116
    mas omite os pinos 20 e 21, e o "Esquema Completo" da revista não
    inclui as 6116; escolhas fundamentadas na tabela-verdade da 6116
    (/OE don't care na escr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
2026-07-18 Registra os capacitores C1-C10 na errata como acréscimo ao artigo
    Nova seção 5 em correcoes-errata.md: o artigo não prevê desacoplamento
    (a montagem original aproveitava o da placa hospedeira); numa placa
    própria os 100nF por CI + 47uF de bulk são necessários e não devem ser
    removidos ao comparar com a revista. descricao-circuito.md passa a
    apenas descrever e apontar para a errata.
2026-07-18 PCB: contorno em T medido sobre o TK-85 e posicionamento completo
    Contorno ancorado no soquete do IC2 (foto da placa calibrada em
    10 px/mm pelo passo dos DIPs; conferida no DIP-40 do Z80):
    - Língua x -10,5..+10 / y -20..+17,5 sobre o IC2, com os dois pentes
    do interposer (pino 1 ao norte, casando com o IC2), U9 e U6
    - Corpo x -70..+35,6 / y +17,5..+59 sobre as fileiras planas de
    TTL/RAM; recorte SE desvia do capacitor de tântalo
    - Fora do contorno: capacitor azul deitado, 2716+soquete, Z80
    - J1 na borda sul com pinos para a frente (fios voadores)
    - Footprints corrigidos no esquema: DIP-14/16 de 7,62 mm (eram
    10,16 mm) e variantes _Socket; netlist re-verificada (idêntica)
    - DRC: 0 v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
    [mod_tk85_hires.kicad_pcb, mod_tk85_hires.kicad_sch]
2026-07-18 Corrige a natureza do IC2 (ROM principal) e registra medição de altura
    - IC2/2364 é a ROM PRINCIPAL do TK-85 (BASIC/sistema + tabelas de
    caracteres, como no ZX81), não uma "ROM de caracteres" dedicada.
    Corrigido em README, descrição do circuito, errata, referências,
    mecânica e na nota 1 do esquema (PDF/SVG reexportados; netlist
    idêntica, ERC 0/0)
    - docs/mecanica.md: medição real do gabinete — ~12 mm livres acima
    da ROM (teto ~17 mm sobre a placa-mãe). A pilha de 2 níveis
    (~20-26 mm) está descartada; opções viáveis: 1 nível + soquete
    extra (vão ~10-11 mm, CIs do mod soldados) mantendo o contorno,
    ou 1 nível simples com contorno redesenhado fora dos ICs 30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
    [mod_tk85_hires.kicad_sch]
2026-07-18 Mecânica: IC2/2716 já são soquetados; teto real ~20-21 mm — pilha decidida
    Correção do usuário: IC2 e IC3 (2716) têm soquetes de lâmina de
    fábrica (a leitura anterior da foto estava errada), e os 12 mm livres
    foram medidos acima da ROM soquetada — o teto é ~20-21 mm, igual
    sobre os ICs 30-37. Decisão final de empilhamento: contorno mantido,
    1 nível + 1 soquete torneado espaçador (vão ~10-11 mm), CIs do mod
    soldados, ROM em soquete de lâmina baixo (~20 mm no topo). Sem
    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
2026-07-19 PCB roteada: 2 camadas, DRC zerado
    Roteamento com Freerouting 2.2.4 via pipeline DSN/SES automatizado
    (placa-isca com contorno recuado 0,35 mm para garantir o isolamento
    de borda; zonas removidas da isca — como plano no DSN elas bloqueiam
    o autorouter; GND roteado como trilha e reforçado por pours nas duas
    faces). Língua do interposer alargada 0,6 mm a oeste para abrir
    corredores. Acabamento: 1 via de GND reposicionada (isolamento de
    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
    [mod_tk85_hires.kicad_pcb]
2026-07-19 Silk: limpeza manual (topo) e pinagem do J1 no verso
    - Limpeza dos textos de silkscreen no topo feita manualmente no
    pcbnew (62 -> 9 avisos, nenhum silk sobre cobre)
    - Novo rótulo espelhado no B.SilkS com a pinagem do J1 (1=A14,
    2=A15, 3=RAM_CS, 4=MREQ, 5=RFSH, 6=WR, 7=CLK_60, 8=CLK_VID),
    posicionado entre as fileiras de pads do U3, sem criar nenhum
    aviso novo de DRC
    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
    [mod_tk85_hires.kicad_pcb]
2026-07-19 Referência do artigo (Datassette) e arquivos de fabricação
    - referencias.md: link do acervo Datassette para consulta do artigo
    original da Microhobby
    - fabricacao/: Gerbers X2 (7 camadas), furação Excellon com mapa,
    zip pronto para fábrica e README com a especificação da placa
    (2 camadas, 1,6 mm, trilha mín. 0,25 mm, isolamento 0,13 mm,
    furo mín. 0,3 mm — dentro do padrão barato de qualquer fabricante)
    [mod_tk85_hires-B_Cu.gbl, mod_tk85_hires-B_Mask.gbs, mod_tk85_hires-B_Silkscreen.gbo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]
2026-07-19 Atualiza o status no topo do README (PCB e Gerbers prontos)
2026-07-19 Referências: links dos datasheets (2364, 6116) e do esquema rev. K
    - ROM 2364: datasheet MOS (fev. 1980) no archive.org
    - SRAM 6116: datasheet Renesas 6116SA/LA
    - Esquema TK-85 rev. K (redesenho de Danjovic) no acervo Datassette
    - Removida a EPROM 2716 (IC3) das referências — não é usada em
    nenhuma parte do projeto (segue citada em mecanica.md apenas como
    obstáculo físico de altura na placa hospedeira)
2026-07-19 RV1 com ajuste por cima (3266W), silk do usuário e opção ROM-na-língua
    - RV1 trocado de Bourns 3266P (lateral — parafuso ficava voltado
    para o interior da placa, inacessível) para 3266W (ajuste pelo
    topo), mantendo os pads 1/2 nas posições originais; /CS0 foi
    re-roteado para liberar o novo pad 3, e o courtyard embutido do
    footprint foi aparado 0,25 mm (corpos reais ficam ~1 mm afastados
    de U1/C9). DRC: 0 violações elétricas, 0 pads desconectados
    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
    [bom.csv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]
2026-07-19 Silk do C10 (usuário) e análise de altura do RV1/ROM-na-língua
    - Ajuste manual do silk do C10 (estava sob o componente)
    - mecanica.md: altura real do 3266W (8,26 mm, do modelo STEP/datasheet)
    — topo a ~19,9-20,9 mm, mesmo grupo crítico da ROM frente ao teto de
    ~20-21 mm; procedimento de ensaio a seco (≥ 8,3 mm livres sobre a
    placa na região do RV1) e planos B documentados
    - Correção de erro de referencial na seção "ROM sobre a língua": o topo
    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
    [mod_tk85_hires.kicad_pcb]
2026-07-19 Regenera Gerbers/furação/PDF com o silk do C10 ajustado
    O acerto do silk do C10 eliminou a última sobreposição de silkscreen
    (silk_overlap zerado; restam só avisos de silk na borda e as térmicas
    conhecidas). Zip de fabricação atualizado.
    [mod_tk85_hires-B_Cu.gbl, mod_tk85_hires-B_Mask.gbs, mod_tk85_hires-B_Silkscreen.gbo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]
2026-07-19 Ajuste de silk do usuário; Gerbers/furação/PDF regenerados
    DRC inalterado no baseline (0 elétrico, 0 desconectados). Zip de
    fabricação atualizado.
    [mod_tk85_hires-B_Cu.gbl, mod_tk85_hires-B_Mask.gbs, mod_tk85_hires-B_Silkscreen.gbo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]
